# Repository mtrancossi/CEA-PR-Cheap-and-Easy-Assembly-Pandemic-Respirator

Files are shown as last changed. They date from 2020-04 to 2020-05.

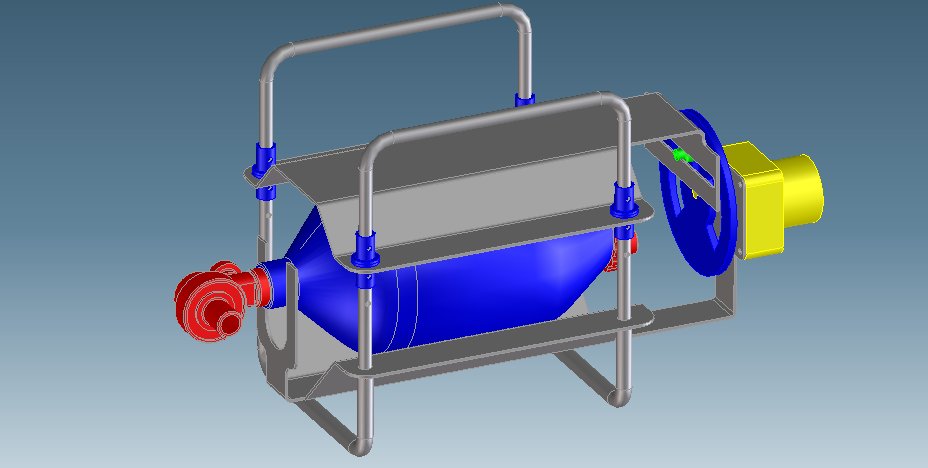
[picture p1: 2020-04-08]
Image3.jpg

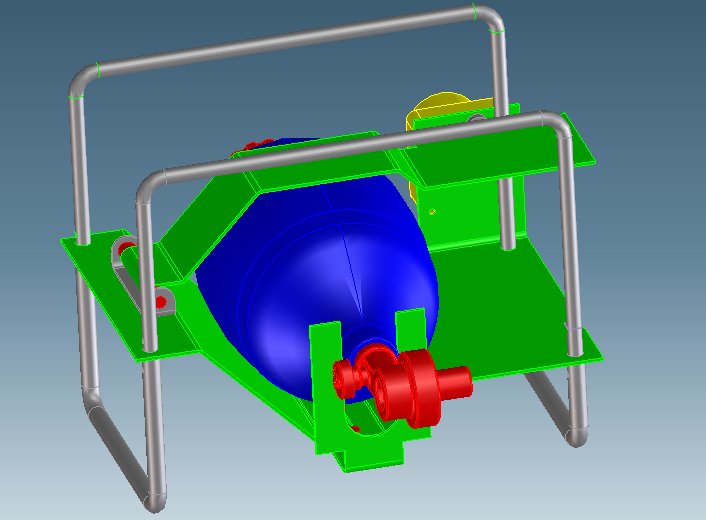
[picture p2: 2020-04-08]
Image13.jpg

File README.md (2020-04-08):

# CEA-PR-Cheap-and-Easy-Assembly-Pandemic-Respirator

This project proposal aim to stimulate the discussion and the work on different models of very traditional and simple pandemic respirators that are simple Ambu actuators that can be manufactured also in poor countries with very traditional technologies.

Details such as screws have not been identified to simplify the drawing of local final versions which could be realized by using locally available items.

The project has been shared open access to ask cooperation in the control area and design improvement. kind regards to anyone who wants to cooperate.

Please notice that when opening into Acrobat the PDF visualization, you need to click on the security bar and recognize the file as secure. otherwise it could not be open and you see only colored balls on the screen.

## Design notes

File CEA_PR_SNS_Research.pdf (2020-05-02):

# CHEAP EASY ASSEMBLY PANDEMIC REPIRATOR

## CEA-PR

## APRIL 19, 2020

SHIVESH NARAYAN SHARMA

Shivesh Narayan Sharma

## Contents

10.2 Calculated values on the basis of different torque and Arm length values (for Pressure

## 1 Abstract

This project proposal aims to stimulate the discussion and the work on different models of very traditional and simple pandemic respirators that are simple Ambu actuators that can be manufactured also in poor countries with very traditional technologies. The ventilation process should be tightly controlled, an uncontrolled pressurization could harm the patient badly and could lead to serious internal injury. This is a preliminary research looking into medical complications of mechanical respiration and improvising the Cheap Easy Assembly Pandemic Respirator (CEA-PR) design in the field of control.

## 2 Hypothesis

The CEA respirator is a motor-operated device, primarily the torque and rpm required to run the machine is an essential value. RPM can be calculated on the basis of no of breathing cycles required in a minute, working out force with help of torque value will help in determining other values. Power of motor can be determined by force and angular velocity.

Compression of Ambu bag plays an essential role in flow rate control, compression can be controlled by force applied pressure control is essential for tidal volume. Both force and pressure can be calculated by velocity and rotating armlength of machine.

Minimum force required to compress the Ambu bag can be identified by using Ideal Gas Law, by identifying internal pressure internal force can be identified. In this case applied force can be assumed greater than the internal force, and further compression calculation can be made. After calculating all the major values pressure, force and RPM can be calculated for execution of a controlled flow rate and tidal volume according to the patient.

## 3 Theory

### 3.1 Medical Point of View

Mechanics of breathing does not allow lungs to inflate like a balloon, when a person breathes his diaphragms contracts along with the intercostal muscles. Which increases the thoracic cavity (the cavity in which lungs resides), this causes increase in volume and decrease in pressure. To equalize the pressure, the lungs expand and equalizes the atmospheric pressure. Hence breathing is control by two muscle groups. The key thing here is that negative pressure initiates the process of inhalation. The exhalation process is exactly reverse of this process, with a small spike above atm to push the air out of the system.

On the other hand, the mechanical ventilation forces the air into the lungs from outside the body and blow lungs like balloon, if this process is not tightly controlled, the air pressure could work against the primary breathing muscles diaphragm and intercostal. This situation could lead to increasing the pressure in the alveoli (over expanding), above their maximum pressure.

Alveoli are the tiny air sacks present in the lungs that are in contact with blood vessels, they are responsible for O2 and CO2 exchange, and diffusion of O2 in the blood. They are very delicate pieces of tissue. The most damage over pressurization could cause is least inflammation, worst rupture. This situation is called Barotrauma. Patients affected by COVID19; in more severe cases it is associated Acute Respiratory Distress Syndrome (ARDS) are more prone to this side effect of mechanical ventilation. The high-end ventilation devices are also controlled very carefully by experienced Doctors, in expensive ventilators the breathing sequence is triggered by the patients.

Other injury due to over pressure, Air to inflate the stomach (gastric insufflation), Lung injury from overstretching (volutrauma).

3.1.1 Tidal Volume
Tidal volume is the air displaced between inspiration and expiration, when no external effort is applied. For a healthy young adult tidal volume is approximately 500 ml per inspiration or 7 ml per kg of body mass. Patients without pre-existing lung disease, VT = 6

ml
kg

to 8

ml
kg

and Respiration rate is 12 to 20 breaths/ min.

Patients with chronic obstructive lung disease requires high enough rate for proper alveolar ventilation, in this case protective lung ventilation applies which ranges from, VT = 6

ml
kg

to 8

ml
kg

and instinct peep does

not create. With ARDS the lung tissues are very vulnerable, permissive hypercapnia technique is applied. In severe cases 5 ml/ kg tidal volume is applied, PH avoids the delivery of high inspiratory pressures and lower the tidal volume. In this situation a higher PEEP is applied, however different types of PEEP levels are required for different situations.

3.1.2 Flow rate
Working out the flow rate for average weighting adult. The average tidal volume is approximately 500 ml per inspiration or 6 to 8 ml/ kg. Normal frequency of breath is 5 to 6 sec per breath, approximately 12 breath per minute. So, calculating flow rate of a 75 kg patient,

Flow rate = Tidal Volume /kg ∗ Respiration rate Equation 1

Protocol states that 15 L/ min flow rate is normal. Keeping control of tidal volume is also important because a higher tidal volume higher than 10 ml/kg increases risk of pulmonary barotrauma.

### 3.2 Engineering point of View

Control of rpm can control compression and volume.

So,

RPM =

Number of Revolution
Time (in minutes)

Equation 2

Speed of the motor is defined for a selected breathing rate, by using rpm value the angular velocity can be calculated,

Angular velocity (ω) =

RPM
60 sec/min

∗ 2π

rad
rev

Equation 3

Linear speed can be calculated by using angular velocity,

v = ω ∗ r Equation 4

Power can be calculated by,

Power (P) = Torque(τ) ∗ AngularVelocity (ω) Equation 5

The calculations present here are theory based, to identify the force applied and power required, first it is the force present inside can be identified. When force and pressure applied will be greater than the inside pressure and force the compression will occur.

For calculating force by using power applied,

Power relates to force and velocity; power is rate of work done,

Pavg = W ∗ ∆t
Equation 6

Work and force have a relation, in our case work done at a constant force,

W = FX∆X Equation 7

where,

FX is force in x direction, ∆X is displacement.

Putting values in, Pavg = W ∗ ∆t
Equation 6

Pavg =

FX∆X

∆t

Pavg = FX

∆X

∆t

where,

∆X

∆t

= Vavg

so,

Pavg = FXVavg

More general outcome or other way,

P = F⃗ ∗ V⃗⃗

P = F ∗ V cos(θ)

If the force and velocity are in the same direction than angle is 0,

cos(0) = 1

So,

P = F ∗ V Equation 8

Pressure applied (Papp) can be calculated by,

Papp =

F
A

Equation 9

Pressure inside the Ambu bag is calculated, here Pin represent pressure inside Ambu bag, Pout represent pressure outside (leaving) the Ambu bag. Similar abbreviation is used in the case of force Fin, Fout, Fapp.

Now for determining the pressure inside the Ambu bag, by using ideal gas law. The temperature used in equation is room temperature 25℃=298.15 K,

By Ideal Gas Law,

PV = nRT

P =

nRT
V

In this case pressure inside,

Pin =

nRT
V

Equation 10

Human respiration is based upon Boyle’s law,

P1V1 = P2V2 Equation 11

## 4 Medical Device Requirement

### 4.1 Complications

One more point which cannot be neglected is due to limited control/ set parameters (cheap ventilators) the entire breathing requirement is analyzed by machine; in this case the patient will take mechanical input weather it is required or not. It is a very uncomfortable and this requires the patient to be heavily sedated. This process could result in worsening the barotrauma, if patient’s diaphragm and intercostal muscles are resisting the inhalation.

### 4.2 Product Design specifications

Table 1 Design specifications

## 5 Device Design

### 5.1 Machine Design

The ventilator consists of two panels, lower panel is fixed and Ambu bag is placed on it. The upper panel is connected with motor on the one side which rotates and on the other side it is connected with hinge mechanism with the lower panel. When rotation takes place the hinge mechanism allows upper panel to move upward and downward, hence the Ambu bag compresses and ventilation takes place.

User specified multiple breath/min settings Multiple tidal volume settings Inspiration/ Expiration ratio Maximum Pressure limiting
Robust Mechanical and Electrical system Minimal Powerd
Provide Mulitple control settings

Medical Requirement

Mechanical

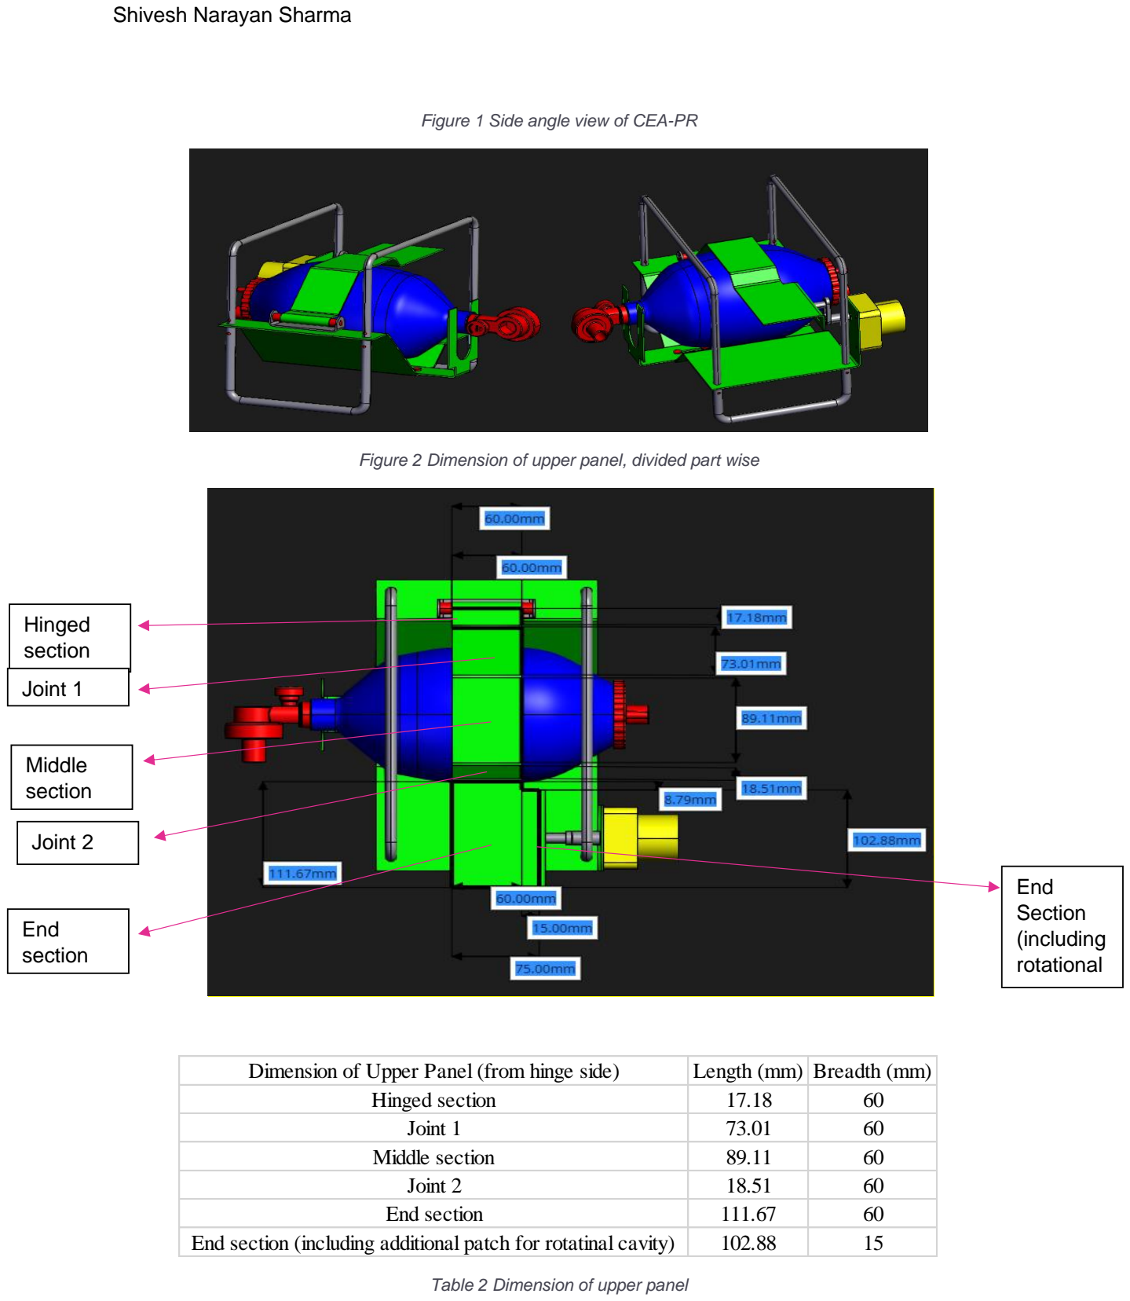
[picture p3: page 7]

Figure 1 Side angle view of CEA-PR

Figure 2 Dimension of upper panel, divided part wise

Table 2 Dimension of upper panel

Dimension of Upper Panel (from hinge side) | Length (mm) | Breadth (mm)
Hinged section | 17.18 | 60
Joint 1 | 73.01 | 60
Middle section | 89.11 | 60
Joint 2 | 18.51 | 60
End section | 111.67 | 60
End section (including additional patch for rotatinal cavity) | 102.88 | 15

Hinged
section

Joint 1

Middle
section

Joint 2

End
section

End
Section
(including
rotational

The sections of upper panel is divided on the basis of joint, it has been divided to understand the dimension of middle section which is creating pressure.

Rotational arm which moves the panel upward and downward = 0.031m = radius of rotating circular path.

### 5.2 Geometry of Ambu Bag

There are two tubing port available on the inlet side, the big port is the reservoir port, small port is for oxygen tubing. On the patient side the expiratory valve is present, for the safety if patient is trying to breath from the other side or putting effort (PEEP valve). Fish mouth valve is present at the patient side, it opens up when the Ambu bag is compressed. For expiration same path is not used, an expiratory duct is present around fish mouth valve. All valves present in the Ambu bag is one-way valves.

Volume of Ambu bag is 1.475 L, according to Ambu website model SPUR II adult resuscitator, with one hand compression releases 800 ml and with two hand compression releases 1100 ml, reservoir volume is 2600 ml and dimension is 295x127 mm.

In this ventilator design Ambu bag can be used with or without oxygen tubing. If patient is critically ill and need 100% of oxygen supply than oxygen tubing can be fitted with reservoir bag. In the case of 100% oxygen delivery if reservoir bag is not attached the open cavity can dilute the oxygen up to 40%, hence the patient will get diluted concentration of oxygen. Whereas using this kit without oxygen supply is also possible as it takes oxygen present in the air.

### 5.3 Selected motor specification

RS Pro Synchronous is the selected motor, the specification is listed below,

Table 3 Specification of motor

## 6 Calculations

The calculation here is based on these values,

Table 4 Values used in calculation

### 6.1 Pressure inside Ambu Bag

From Pin =

nRT
V

Equation 10

Output Speed | 20 rpm
Supply Voltage | 230 V
Maximum Output Torque | 0.016 Nm
Dimension | 60x60x49.5 mm
Gear Ratio | 25:01:00
Weight | 75 Kg
Tidal Volume | 6 ml
Respiration Rate | 12
Temperature | 25˚C (298.15 K)
Torque | 0.016 Nm
Density | 1.225
Radius | 0.031 m

Where,

R = 0.08206, V = 1.475 L (see section description), T = 298.15 K, n (no. of moles) =? ρ =1.225,

no. of moles can be calculated by identifying mass of gas which can identify moles,

so,

m = ρV Equation 12

√V

3 = √1.475 ³

V = 1.3832

Putting value m = ρV Equation 12

m = 1.225 ∗ 1.3832 = 1.80688 gm

= 0.00180688 kg

Air molecular mass = 28.9647 gm/mol

So, by dividing mass of air = 1.80688 gm by molar mass of air 28.9647 gm/ mol we can get no. of moles,

n =

1.80688 gm
28.9647 gm/mol

n = 0.0623821 mol

Substituting the values in eq (10),

Pin =

0.06238 ∗ 0.08206 ∗ 298.15 1.3832

Pin = 1.1278 Pa

Is the pressure present inside the Ambu bag is Pin known, for compression Papp > Pin.

Rpm can be defined by respiratory rate so,

if one round per second,tℎan in a minute = 60 rpm,

by using normal breatℎing rate = 12 breaths per minute (5 sec interval)

= 12 rpm

Flow rate calculation,

Substituting values in Flow rate = Tidal Volume /kg ∗ Respiration rate Equation 1

Taking least here 6 ml per kg so,

= 6

ml
kg ∗ 75kg

= 450 ml = 0.45 L

Flow rate = 0.45 ∗ 12 = 5.41 L/min

Table 5 Flow rate calculated values

Calculating angular velocity on the basis of rpm by equation (3),

ω =

12
60 sec/min

∗ 2π

rad
rev

ω = 1.256 rad/sec

Linear velocity by v = ω ∗ r Equation 4,

v = 1.256 ∗ 0.031 = 0.038

m
s
Calculating Power by Power (P) = Torque(τ) ∗ AngularVelocity (ω) Equation 5

P = 1.256 ∗ 0.016 = 0.020096 W

Force applied (Fapp) can be calculated by P = F ∗ V Equation 8,

Fapp =

0.020096
0.038 = 0.49 N

For Pressure (Papp) by equation (9), value of area is taken from (Table 1) middle section,

Papp =

0.49
0.005346 = 91.65731 Pa

Table 6 Angular velocity, Linear velocity, Power, Applied force and power calculated values.

The pressure value here is applied pressure and force is applied force

Weight | Tidal Volume | RR | Flow Rate
75 | 6 | 12 | 5.4
75 | 6 | 14 | 6.3
75 | 6 | 16 | 7.2
75 | 6 | 18 | 8.1
75 | 6 | 20 | 9
75 | 6 | 22 | 9.9
75 | 6 | 24 | 10.8

Tidal Volume 6

2pi | sec/min | R (m) | Torque (Nm) | RPM | Angular Velocity (rad/sec) | Velocity (m/s) | Power (W) | Force (N) | Area (m^2) | Pressure (Pa)
6.283185307 | 60 | 0.031 | 0.016 | 12 | 1.256637061 | 0.038955749 | 0.020106193 | 0.516129 | 0.005346 | 96.54489941
6.283185307 | 60 | 0.031 | 0.016 | 14 | 1.466076572 | 0.045448374 | 0.023457225 | 0.516129 | 0.005346 | 96.54489941
6.283185307 | 60 | 0.031 | 0.016 | 16 | 1.675516082 | 0.051940999 | 0.026808257 | 0.516129 | 0.005346 | 96.54489941
6.283185307 | 60 | 0.031 | 0.016 | 18 | 1.884955592 | 0.058433623 | 0.030159289 | 0.516129 | 0.005346 | 96.54489941
6.283185307 | 60 | 0.031 | 0.016 | 20 | 2.094395102 | 0.064926248 | 0.033510322 | 0.516129 | 0.005346 | 96.54489941

Arm Length 0.031 m

## 7 Specifications

### 7.1 Machine Control

The primary guidance is to limit the volume and pressure of air entering the lungs. In every action speed of the upper panel of the machine is going to be constant, because more force can lead to more pressure (force is directly proportional to the pressure), which can disturb the flow rate. With constant speed flow rate can be constant. For increase breath/ minute or respiratory rate (RR) interval of the mechanism could be increased. So, Respiration rate can be controlled by rpm, torque value can control applied pressure and force.

In the preliminary research it was found that limiting the compression with the force and pressure was impossible in this kind of mechanism, the compression was the result of rotation. So, in this case it does not matter how much force is applied regardless of the force the arm will rotate and the panel will go downward. It means that the Radius of circular path (R) or the rotating arm controls the compression. For different values of compression (flow rate) the radius of the circular path could decrease (size of the rotating arm could be decreased).

As an Assumption,

if compression by 0.031m rotating arm ≈ two hand compression of ambu bag 1100 ml

that rotating arm size can be assumed by equating, the required flow rate to the upper expression.

So, arm size for a 0.45 L (from the above flow rate calculation),

Let arm size be x,

1.1 L
0.45 L

=

0.031 m
x

x = 0.0126 m.

By this assumption flow rate can be controlled according to the patient’s conditions with multiple possibilities of settings. In this report few rotating arm sizes have been used in calculation and the data has been presented under appendix section. All other required arm sizes can be calculated by using similar approach.

For increase in Tidal volume pressure of the cam can be increased, but speed of the upper panel should be constant, by using pressure compression of the Ambu bag can be controlled which is responsible for tidal volume.

As it can be seen that different tidal volume and weight combinations requires different arm length, in thus case a new design can be introduced based upon watch strap. Where holes can be marked on the scaled positions according to arm length calculation and the little part which moves back and forth on the upper panel. Could be removed and fix (using a nut) to required position.

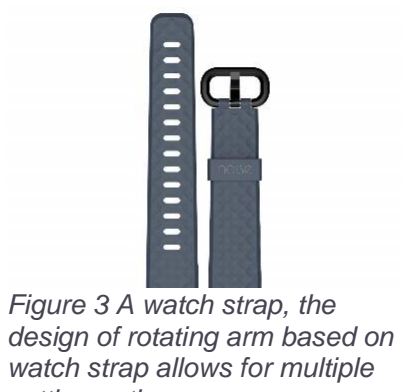
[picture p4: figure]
Figure 3 A watch strap, the design of rotating arm based on watch strap allows for multiple

setting options

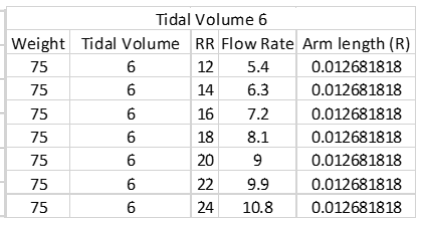
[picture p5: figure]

Table 7 CEA-PR controls | Table 8 Arm length according to flow rate

## 8 Conclusion

The result obtained here are based on the theoretical evaluation. Entire set of result is available in the Appendix section, according to research and calculations the CEA-PR can provide multiple settings of flow rate, tidal volume and pressure control. It can provide aid to an ARDS affected patient which requires low inspiratory pressure and high tidal volume as well as to a patient who requires normal tidal volume and high flow rate. All the data is tabulated according to different weight and different torque values, in which different settings and their outcome which can be achieved by machine is present. The ‘R’ in the table represents radius of the circular path or the rotating arm.

## 9 References

PDS Requirement | Controled Via
User Specified breath/ min | RPM
Tidal volume | Rotational Arm
Maximum Pressure Limiting | Torque
Flow Rate | Rotational Arm
RPM

## 10 Appendix

Radius of circular path or rotating arm length (R) is measured in m.

### 10.1 Calculated flow control and Arm length Value (for compression)

10.1.1 Weight 60

10.1.2 Weight 70

Tidal Volume 5 | Tidal Volume 6
Weight | Tidal Volume | RR | Flow Rate | Arm length (R) | Weight | Tidal Volume | RR | Flow Rate | Arm length (R)
60 | 5 | 12 | 3.6 | 0.008454545 | 60 | 6 | 12 | 4.32 | 0.010145455
60 | 5 | 14 | 4.2 | 0.008454545 | 60 | 6 | 14 | 5.04 | 0.010145455
60 | 5 | 16 | 4.8 | 0.008454545 | 60 | 6 | 16 | 5.76 | 0.010145455
60 | 5 | 18 | 5.4 | 0.008454545 | 60 | 6 | 18 | 6.48 | 0.010145455
60 | 5 | 20 | 6 | 0.008454545 | 60 | 6 | 20 | 7.2 | 0.010145455
60 | 5 | 22 | 6.6 | 0.008454545 | 60 | 6 | 22 | 7.92 | 0.010145455
60 | 5 | 24 | 7.2 | 0.008454545 | 60 | 6 | 24 | 8.64 | 0.010145455
Tidal Volume 7 | Tidal Volume 8
Weight | Tidal Volume | RR | Flow Rate | Arm length (R) | Weight | Tidal Volume | RR | Flow Rate | Arm length (R)
60 | 7 | 12 | 5.04 | 0.011836364 | 60 | 8 | 12 | 5.76 | 0.013527273
60 | 7 | 14 | 5.88 | 0.011836364 | 60 | 8 | 14 | 6.72 | 0.013527273
60 | 7 | 16 | 6.72 | 0.011836364 | 60 | 8 | 16 | 7.68 | 0.013527273
60 | 7 | 18 | 7.56 | 0.011836364 | 60 | 8 | 18 | 8.64 | 0.013527273
60 | 7 | 20 | 8.4 | 0.011836364 | 60 | 8 | 20 | 9.6 | 0.013527273
60 | 7 | 22 | 9.24 | 0.011836364 | 60 | 8 | 22 | 10.56 | 0.013527273
60 | 7 | 24 | 10.08 | 0.011836364 | 60 | 8 | 24 | 11.52 | 0.013527273
Tidal Volume 5 | Tidal Volume 6
Weight | Tidal Volume | RR | Flow Rate | Arm length (R) | Weight | Tidal Volume | RR | Flow Rate | Arm length (R)
70 | 5 | 12 | 4.2 | 0.009863636 | 70 | 6 | 12 | 5.04 | 0.011836364
70 | 5 | 14 | 4.9 | 0.009863636 | 70 | 6 | 14 | 5.88 | 0.011836364
70 | 5 | 16 | 5.6 | 0.009863636 | 70 | 6 | 16 | 6.72 | 0.011836364
70 | 5 | 18 | 6.3 | 0.009863636 | 70 | 6 | 18 | 7.56 | 0.011836364
70 | 5 | 20 | 7 | 0.009863636 | 70 | 6 | 20 | 8.4 | 0.011836364
70 | 5 | 22 | 7.7 | 0.009863636 | 70 | 6 | 22 | 9.24 | 0.011836364
70 | 5 | 24 | 8.4 | 0.009863636 | 70 | 6 | 24 | 10.08 | 0.011836364
Tidal Volume 7 | Tidal Volume 8
Weight | Tidal Volume | RR | Flow rate | Arm length (R) | Weight | Tidal Volume | RR | Flow Rate | Arm length (R)
70 | 7 | 12 | 5.88 | 0.013809091 | 70 | 8 | 12 | 6.72 | 0.015781818
70 | 7 | 14 | 6.86 | 0.013809091 | 70 | 8 | 14 | 7.84 | 0.015781818
70 | 7 | 16 | 7.84 | 0.013809091 | 70 | 8 | 16 | 8.96 | 0.015781818
70 | 7 | 18 | 8.82 | 0.013809091 | 70 | 8 | 18 | 10.08 | 0.015781818
70 | 7 | 20 | 9.8 | 0.013809091 | 70 | 8 | 20 | 11.2 | 0.015781818
70 | 7 | 22 | 10.78 | 0.013809091 | 70 | 8 | 22 | 12.32 | 0.015781818
70 | 7 | 24 | 11.76 | 0.013809091 | 70 | 8 | 24 | 13.44 | 0.015781818

10.1.3 Weight 75

10.1.4 Weight 80

Tidal Volume 5 | Tidal Volume 6
Weight | Tidal Volume | RR | Flow Rate | Arm length (R) | Weight | Tidal Volume | RR | Flow Rate | Arm length (R)
75 | 5 | 12 | 4.5 | 0.010568182 | 75 | 6 | 12 | 5.4 | 0.012681818
75 | 5 | 14 | 5.25 | 0.010568182 | 75 | 6 | 14 | 6.3 | 0.012681818
75 | 5 | 16 | 6 | 0.010568182 | 75 | 6 | 16 | 7.2 | 0.012681818
75 | 5 | 18 | 6.75 | 0.010568182 | 75 | 6 | 18 | 8.1 | 0.012681818
75 | 5 | 20 | 7.5 | 0.010568182 | 75 | 6 | 20 | 9 | 0.012681818
75 | 5 | 22 | 8.25 | 0.010568182 | 75 | 6 | 22 | 9.9 | 0.012681818
75 | 5 | 24 | 9 | 0.010568182 | 75 | 6 | 24 | 10.8 | 0.012681818
Tidal Volume 7 | Tidal Volume 8
Weight | Tidal Volume | RR | Flow rate | Arm length (R) | Weight | Tidal volume | RR | Flow Rate | Arm length (R)
75 | 7 | 12 | 6.3 | 0.014795455 | 75 | 8 | 12 | 7.2 | 0.016909091
75 | 7 | 14 | 7.35 | 0.014795455 | 75 | 8 | 14 | 8.4 | 0.016909091
75 | 7 | 16 | 8.4 | 0.014795455 | 75 | 8 | 16 | 9.6 | 0.016909091
75 | 7 | 18 | 9.45 | 0.014795455 | 75 | 8 | 18 | 10.8 | 0.016909091
75 | 7 | 20 | 10.5 | 0.014795455 | 75 | 8 | 20 | 12 | 0.016909091
75 | 7 | 22 | 11.55 | 0.014795455 | 75 | 8 | 22 | 13.2 | 0.016909091
75 | 7 | 24 | 12.6 | 0.014795455 | 75 | 8 | 24 | 14.4 | 0.016909091
Tidal Volume 5 | Tidal Volume 6
Weight | Tidal Volume | RR | Flow Rate | Arm length (R) | Weight | Tidal Volume | RR | Flow Rate | Arm length (R)
80 | 5 | 12 | 4.8 | 0.011272727 | 80 | 6 | 12 | 5.76 | 0.013527273
80 | 5 | 14 | 5.6 | 0.011272727 | 80 | 6 | 14 | 6.72 | 0.013527273
80 | 5 | 16 | 6.4 | 0.011272727 | 80 | 6 | 16 | 7.68 | 0.013527273
80 | 5 | 18 | 7.2 | 0.011272727 | 80 | 6 | 18 | 8.64 | 0.013527273
80 | 5 | 20 | 8 | 0.011272727 | 80 | 6 | 20 | 9.6 | 0.013527273
80 | 5 | 22 | 8.8 | 0.011272727 | 80 | 6 | 22 | 10.56 | 0.013527273
80 | 5 | 24 | 9.6 | 0.011272727 | 80 | 6 | 24 | 11.52 | 0.013527273
Tidal Volume 7 | | | | | Tidal Volume 8
Weight | Tidal Volume | RR | Flow Rate | Arm length (R) | Weight | Tidal Volume | RR | Flow Rate | Arm length (R)
80 | 7 | 12 | 6.72 | 0.015781818 | 80 | 8 | 12 | 7.68 | 0.018036364
80 | 7 | 14 | 7.84 | 0.015781818 | 80 | 8 | 14 | 8.96 | 0.018036364
80 | 7 | 16 | 8.96 | 0.015781818 | 80 | 8 | 16 | 10.24 | 0.018036364
80 | 7 | 18 | 10.08 | 0.015781818 | 80 | 8 | 18 | 11.52 | 0.018036364
80 | 7 | 20 | 11.2 | 0.015781818 | 80 | 8 | 20 | 12.8 | 0.018036364
80 | 7 | 22 | 12.32 | 0.015781818 | 80 | 8 | 22 | 14.08 | 0.018036364
80 | 7 | 24 | 13.44 | 0.015781818 | 80 | 8 | 24 | 15.36 | 0.018036364

10.1.5 Weight 90

### 10.2 Calculated values on the basis of different torque and Arm length values (for Pressure and Force control)

10.2.1 Torque 0.01
The area mentioned in the table is upper panel Table 2 (middle section) area, Force is applied force and pressure is applied pressure.

10.2.2 Torque 0.012

Tidal Volume 5 | Tidal Volume 6
Weight | Tidal Volume | RR | Flow Rate | Arm length (R) | Weight | Tidal Volume | RR | Flow Rate | Arm length (R)
90 | 5 | 12 | 5.4 | 0.012681818 | 90 | 6 | 12 | 6.48 | 0.015218182
90 | 5 | 14 | 6.3 | 0.012681818 | 90 | 6 | 14 | 7.56 | 0.015218182
90 | 5 | 16 | 7.2 | 0.012681818 | 90 | 6 | 16 | 8.64 | 0.015218182
90 | 5 | 18 | 8.1 | 0.012681818 | 90 | 6 | 18 | 9.72 | 0.015218182
90 | 5 | 20 | 9 | 0.012681818 | 90 | 6 | 20 | 10.8 | 0.015218182
90 | 5 | 22 | 9.9 | 0.012681818 | 90 | 6 | 22 | 11.88 | 0.015218182
90 | 5 | 24 | 10.8 | 0.012681818 | 90 | 6 | 24 | 12.96 | 0.015218182
Tidal Volume 7 | | | | | Tidal Volume 8
Weight | Tidal Volume | RR | Flow rate | Arm length (R) | Weight | Tidal volume | RR | Flow Rate | Arm length (R)
90 | 7 | 12 | 7.56 | 0.017754545 | 90 | 8 | 12 | 8.64 | 0.020290909
90 | 7 | 14 | 8.82 | 0.017754545 | 90 | 8 | 14 | 10.08 | 0.020290909
90 | 7 | 16 | 10.08 | 0.017754545 | 90 | 8 | 16 | 11.52 | 0.020290909
90 | 7 | 18 | 11.34 | 0.017754545 | 90 | 8 | 18 | 12.96 | 0.020290909
90 | 7 | 20 | 12.6 | 0.017754545 | 90 | 8 | 20 | 14.4 | 0.020290909
90 | 7 | 22 | 13.86 | 0.017754545 | 90 | 8 | 22 | 15.84 | 0.020290909
90 | 7 | 24 | 15.12 | 0.017754545 | 90 | 8 | 24 | 17.28 | 0.020290909
2pi | sec/min | R (m) | Torque (Nm) | RPM | Angular Velocity (rad/sec) | Velocity (m/s) | Power (W) | Force (N) | Area (m^2) | Pressure (Pa)
6.283185 | 60 | 0.015 | 0.01 | 12 | 1.256637061 | 0.018849556 | 0.012566371 | 0.666666667 | 0.005346 | 124.7038284
6.283185 | 60 | 0.015 | 0.01 | 14 | 1.466076572 | 0.021991149 | 0.014660766 | 0.666666667 | 0.005346 | 124.7038284
6.283185 | 60 | 0.015 | 0.01 | 16 | 1.675516082 | 0.025132741 | 0.016755161 | 0.666666667 | 0.005346 | 124.7038284
6.283185 | 60 | 0.015 | 0.01 | 18 | 1.884955592 | 0.028274334 | 0.018849556 | 0.666666667 | 0.005346 | 124.7038284
6.283185 | 60 | 0.015 | 0.01 | 20 | 2.094395102 | 0.031415927 | 0.020943951 | 0.666666667 | 0.005346 | 124.7038284

Arm Length 0.015 m

2pi | sec/min | R (m) | Torque (Nm) | RPM | Angular Velocity (rad/sec) | Velocity (m/s) | Power (W) | Force (N) | Area (m^2) | Pressure (Pa)
6.283185 | 60 | 0.02 | 0.01 | 12 | 1.256637061 | 0.025132741 | 0.012566371 | 0.5 | 0.005346 | 93.52787131
6.283185 | 60 | 0.02 | 0.01 | 14 | 1.466076572 | 0.029321531 | 0.014660766 | 0.5 | 0.005346 | 93.52787131
6.283185 | 60 | 0.02 | 0.01 | 16 | 1.675516082 | 0.033510322 | 0.016755161 | 0.5 | 0.005346 | 93.52787131
6.283185 | 60 | 0.02 | 0.01 | 18 | 1.884955592 | 0.037699112 | 0.018849556 | 0.5 | 0.005346 | 93.52787131
6.283185 | 60 | 0.02 | 0.01 | 20 | 2.094395102 | 0.041887902 | 0.020943951 | 0.5 | 0.005346 | 93.52787131

Arm Length 0.02 m

2pi | sec/min | R (m) | Torque (Nm) | RPM | Angular Velocity (rad/sec) | Velocity (m/s) | Power (W) | Force (N) | Area (m^2) | Pressure (Pa)
6.283185 | 60 | 0.031 | 0.01 | 12 | 1.256637061 | 0.038955749 | 0.012566371 | 0.322580645 | 0.005346 | 60.34056213
6.283185 | 60 | 0.031 | 0.01 | 14 | 1.466076572 | 0.045448374 | 0.014660766 | 0.322580645 | 0.005346 | 60.34056213
6.283185 | 60 | 0.031 | 0.01 | 16 | 1.675516082 | 0.051940999 | 0.016755161 | 0.322580645 | 0.005346 | 60.34056213
6.283185 | 60 | 0.031 | 0.01 | 18 | 1.884955592 | 0.058433623 | 0.018849556 | 0.322580645 | 0.005346 | 60.34056213
6.283185 | 60 | 0.031 | 0.01 | 20 | 2.094395102 | 0.064926248 | 0.020943951 | 0.322580645 | 0.005346 | 60.34056213

Arm Length 0.031 m

2pi | sec/min | R (m) | Torque (Nm) | RPM | Angular Velocity (rad/sec) | Velocity (m/s) | Power (W) | Force (N) | Area (m^2) | Pressure (Pa)
6.283185 | 60 | 0.015 | 0.012 | 12 | 1.256637061 | 0.018849556 | 0.015079645 | 0.8 | 0.005346 | 149.6445941
6.283185 | 60 | 0.015 | 0.012 | 14 | 1.466076572 | 0.021991149 | 0.017592919 | 0.8 | 0.005346 | 149.6445941
6.283185 | 60 | 0.015 | 0.012 | 16 | 1.675516082 | 0.025132741 | 0.020106193 | 0.8 | 0.005346 | 149.6445941
6.283185 | 60 | 0.015 | 0.012 | 18 | 1.884955592 | 0.028274334 | 0.022619467 | 0.8 | 0.005346 | 149.6445941
6.283185 | 60 | 0.015 | 0.012 | 20 | 2.094395102 | 0.031415927 | 0.025132741 | 0.8 | 0.005346 | 149.6445941

Arm Length 0.015 m

10.2.3 Torque 0.014

2pi | sec/min | R (m) | Torque (Nm) | RPM | Angular Velocity (rad/sec) | Velocity (m/s) | Power (W) | Force (N) | Area (m^2) | Pressure (Pa)
6.283185 | 60 | 0.02 | 0.012 | 12 | 1.256637061 | 0.025132741 | 0.015079645 | 0.6 | 0.005346 | 112.2334456
6.283185 | 60 | 0.02 | 0.012 | 14 | 1.466076572 | 0.029321531 | 0.017592919 | 0.6 | 0.005346 | 112.2334456
6.283185 | 60 | 0.02 | 0.012 | 16 | 1.675516082 | 0.033510322 | 0.020106193 | 0.6 | 0.005346 | 112.2334456
6.283185 | 60 | 0.02 | 0.012 | 18 | 1.884955592 | 0.037699112 | 0.022619467 | 0.6 | 0.005346 | 112.2334456
6.283185 | 60 | 0.02 | 0.012 | 20 | 2.094395102 | 0.041887902 | 0.025132741 | 0.6 | 0.005346 | 112.2334456

Arm Length 0.02 m

2pi | sec/min | R (m) | Torque (Nm) | RPM | Angular Velocity (rad/sec) | Velocity (m/s) | Power (W) | Force (N) | Area (m^2) | Pressure (Pa)
6.283185 | 60 | 0.031 | 0.012 | 12 | 1.256637061 | 0.038955749 | 0.015079645 | 0.387097 | 0.005346 | 72.40867456
6.283185 | 60 | 0.031 | 0.012 | 14 | 1.466076572 | 0.045448374 | 0.017592919 | 0.387097 | 0.005346 | 72.40867456
6.283185 | 60 | 0.031 | 0.012 | 16 | 1.675516082 | 0.051940999 | 0.020106193 | 0.387097 | 0.005346 | 72.40867456
6.283185 | 60 | 0.031 | 0.012 | 18 | 1.884955592 | 0.058433623 | 0.022619467 | 0.387097 | 0.005346 | 72.40867456
6.283185 | 60 | 0.031 | 0.012 | 20 | 2.094395102 | 0.064926248 | 0.025132741 | 0.387097 | 0.005346 | 72.40867456

Arm Length 0.031 m

2pi | sec/min | R (m) | Torque (Nm) | RPM | Angular Velocity (rad/sec) | Velocity (m/s) | Power (W) | Force (N) | Area (m^2) | Pressure (Pa)
6.283185 | 60 | 0.015 | 0.014 | 12 | 1.256637061 | 0.018849556 | 0.017592919 | 0.933333 | 0.005346 | 174.5853598
6.283185 | 60 | 0.015 | 0.014 | 14 | 1.466076572 | 0.021991149 | 0.020525072 | 0.933333 | 0.005346 | 174.5853598
6.283185 | 60 | 0.015 | 0.014 | 16 | 1.675516082 | 0.025132741 | 0.023457225 | 0.933333 | 0.005346 | 174.5853598
6.283185 | 60 | 0.015 | 0.014 | 18 | 1.884955592 | 0.028274334 | 0.026389378 | 0.933333 | 0.005346 | 174.5853598
6.283185 | 60 | 0.015 | 0.014 | 20 | 2.094395102 | 0.031415927 | 0.029321531 | 0.933333 | 0.005346 | 174.5853598

Arm Length 0.015 m

2pi | sec/min | R (m) | Torque (Nm) | RPM | Angular Velocity (rad/sec) | Velocity (m/s) | Power (W) | Force (N) | Area (m^2) | Pressure (Pa)
6.283185 | 60 | 0.02 | 0.014 | 12 | 1.256637061 | 0.025132741 | 0.017592919 | 0.7 | 0.005346 | 130.9390198
6.283185 | 60 | 0.02 | 0.014 | 14 | 1.466076572 | 0.029321531 | 0.020525072 | 0.7 | 0.005346 | 130.9390198
6.283185 | 60 | 0.02 | 0.014 | 16 | 1.675516082 | 0.033510322 | 0.023457225 | 0.7 | 0.005346 | 130.9390198
6.283185 | 60 | 0.02 | 0.014 | 18 | 1.884955592 | 0.037699112 | 0.026389378 | 0.7 | 0.005346 | 130.9390198
6.283185 | 60 | 0.02 | 0.014 | 20 | 2.094395102 | 0.041887902 | 0.029321531 | 0.7 | 0.005346 | 130.9390198

Arm Length 0.02 m

2pi | sec/min | R (m) | Torque (Nm) | RPM | Angular Velocity (rad/sec) | Velocity (m/s) | Power (W) | Force (N) | Area (m^2) | Pressure (Pa)
6.283185 | 60 | 0.031 | 0.014 | 12 | 1.256637061 | 0.038955749 | 0.017592919 | 0.451613 | 0.005346 | 84.47678699
6.283185 | 60 | 0.031 | 0.014 | 14 | 1.466076572 | 0.045448374 | 0.020525072 | 0.451613 | 0.005346 | 84.47678699
6.283185 | 60 | 0.031 | 0.014 | 16 | 1.675516082 | 0.051940999 | 0.023457225 | 0.451613 | 0.005346 | 84.47678699
6.283185 | 60 | 0.031 | 0.014 | 18 | 1.884955592 | 0.058433623 | 0.026389378 | 0.451613 | 0.005346 | 84.47678699
6.283185 | 60 | 0.031 | 0.014 | 20 | 2.094395102 | 0.064926248 | 0.029321531 | 0.451613 | 0.005346 | 84.47678699

Arm Length 0.031 m

10.2.4 Torque 0.016

2pi | sec/min | R (m) | Torque (Nm) | RPM | Angular Velocity (rad/sec) | Velocity (m/s) | Power (W) | Force (N) | Area (m^2) | Pressure (Pa)
6.283185307 | 60 | 0.015 | 0.016 | 12 | 1.256637061 | 0.018849556 | 0.020106193 | 1.066667 | 0.005346 | 199.5261255
6.283185307 | 60 | 0.015 | 0.016 | 14 | 1.466076572 | 0.021991149 | 0.023457225 | 1.066667 | 0.005346 | 199.5261255
6.283185307 | 60 | 0.015 | 0.016 | 16 | 1.675516082 | 0.025132741 | 0.026808257 | 1.066667 | 0.005346 | 199.5261255
6.283185307 | 60 | 0.015 | 0.016 | 18 | 1.884955592 | 0.028274334 | 0.030159289 | 1.066667 | 0.005346 | 199.5261255
6.283185307 | 60 | 0.015 | 0.016 | 20 | 2.094395102 | 0.031415927 | 0.033510322 | 1.066667 | 0.005346 | 199.5261255

Arm Length 0.015 m

2pi | sec/min | R (m) | Torque (Nm) | RPM | Angular Velocity (rad/sec) | Velocity (m/s) | Power (W) | Force (N) | Area (m^2) | Pressure (Pa)
6.283185307 | 60 | 0.02 | 0.016 | 12 | 1.256637061 | 0.025132741 | 0.020106193 | 0.8 | 0.005346 | 149.6445941
6.283185307 | 60 | 0.02 | 0.016 | 14 | 1.466076572 | 0.029321531 | 0.023457225 | 0.8 | 0.005346 | 149.6445941
6.283185307 | 60 | 0.02 | 0.016 | 16 | 1.675516082 | 0.033510322 | 0.026808257 | 0.8 | 0.005346 | 149.6445941
6.283185307 | 60 | 0.02 | 0.016 | 18 | 1.884955592 | 0.037699112 | 0.030159289 | 0.8 | 0.005346 | 149.6445941
6.283185307 | 60 | 0.02 | 0.016 | 20 | 2.094395102 | 0.041887902 | 0.033510322 | 0.8 | 0.005346 | 149.6445941

Arm Length 0.02 m

2pi | sec/min | R (m) | Torque (Nm) | RPM | Angular Velocity (rad/sec) | Velocity (m/s) | Power (W) | Force (N) | Area (m^2) | Pressure (Pa)
6.283185307 | 60 | 0.031 | 0.016 | 12 | 1.256637061 | 0.038955749 | 0.020106193 | 0.516129 | 0.005346 | 96.54489941
6.283185307 | 60 | 0.031 | 0.016 | 14 | 1.466076572 | 0.045448374 | 0.023457225 | 0.516129 | 0.005346 | 96.54489941
6.283185307 | 60 | 0.031 | 0.016 | 16 | 1.675516082 | 0.051940999 | 0.026808257 | 0.516129 | 0.005346 | 96.54489941
6.283185307 | 60 | 0.031 | 0.016 | 18 | 1.884955592 | 0.058433623 | 0.030159289 | 0.516129 | 0.005346 | 96.54489941
6.283185307 | 60 | 0.031 | 0.016 | 20 | 2.094395102 | 0.064926248 | 0.033510322 | 0.516129 | 0.005346 | 96.54489941

Arm Length 0.031 m

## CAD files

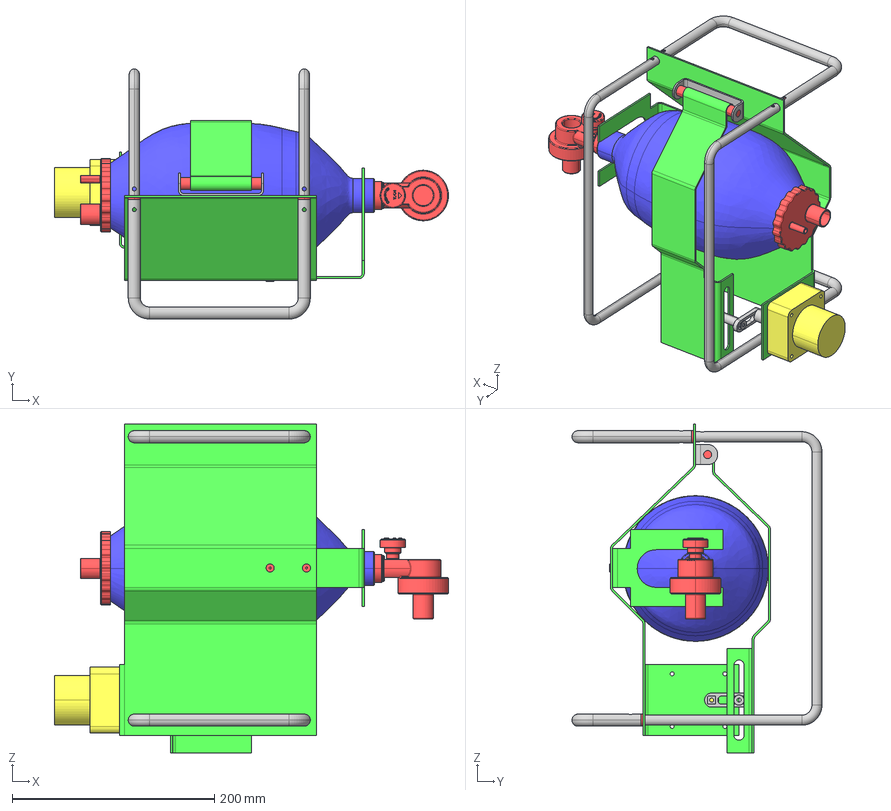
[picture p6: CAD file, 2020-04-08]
Resp5.stp
389.2 x 247.0 x 324.5 mm
Top_Link.2 x 2
pin x 2
p3.2 x 2
pin.1 x 2
a3_a1_Ambubag2.STEP_Ambubag2_butelie_2
a3_a1_Ambubag2.STEP_Ambubag2_ambubag_part
a3_a1_Ambubag2.STEP_Ambubag2_AMBU_BAG1
Sheet.1 x 2
a3_p4.6
Pin_motion
Crank.1
a3_Motor
Crank
Dist
Crank_pin
a3_Motor.1
Dist.3 x 2
Dist.1 x 2
Sheet

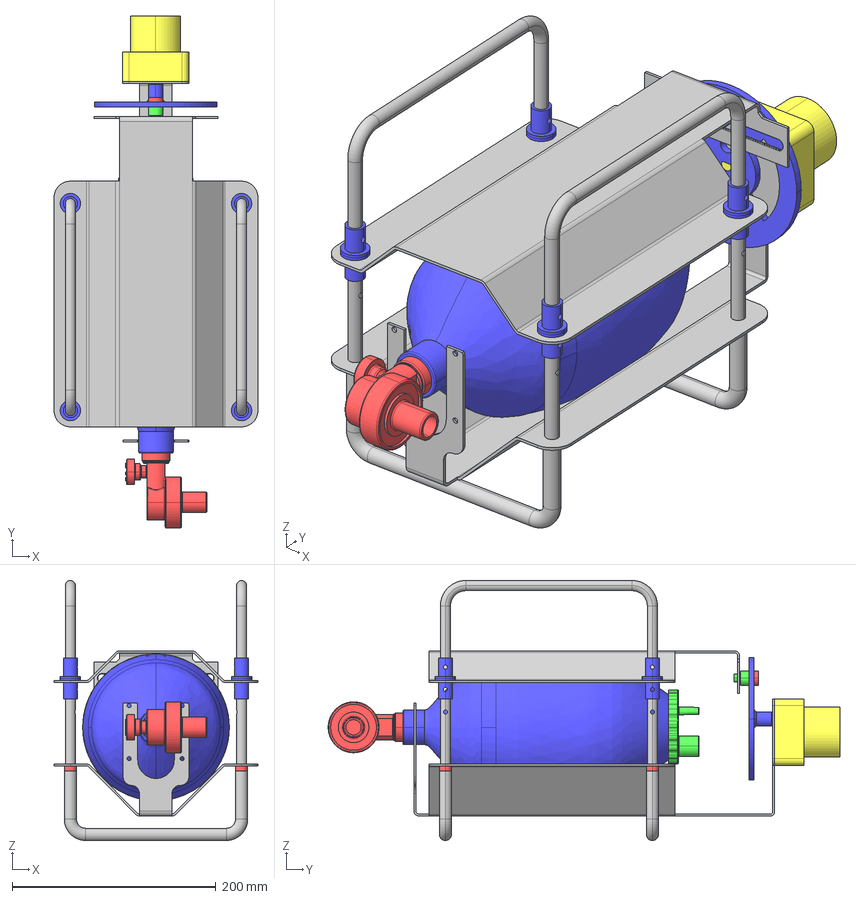
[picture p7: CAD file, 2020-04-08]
RESP3.stp
200.0 x 501.9 x 255.0 mm
Disk_pin
Disk
a3_Motor.1
tubo_top.1.1 x 2
p3.1 x 2
P2.1
p2
bussola1 x 4
boccola_top x 8
Ambubag2.STEP_Ambubag2_AMBU_BAG1
Ambubag2.STEP_Ambubag2_ambubag_part
Ambubag2.STEP_Ambubag2_butelie_2
Disk_pin_2

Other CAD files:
resp3.FCStd
resp5.FCStd

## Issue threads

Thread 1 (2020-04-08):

Possible issues

Pigrenok, 2020-04-08:
Hi, Michele! Nice to hear from you.

I know how badly your country is affected and this ventilator can be a solution. It is very important development in my opinion.

Look, I can see a couple of possible issues with it:
1) You drive the top plate (which is pushing onto Ambu bag) only on one side. This will create significant moment, which will lower the motor side of the plate and raise the other (let's call it valve side) of the plate, effectively constricting it. To avoid it, you need very high precision sliding joints of the top plate and possibly very high quality linear bearings. And that will make the design so much more expensive.
2) As far as I know, Ambu bags are made specifically to be pushed by hands predominantly in the middle. You are pushing it evenly on the whole bag. I believe, the centre of the bag is soft whereas the ends are much more rigid, so, you will need much more power to push it evenly.
3) The other issue is that as far as I know, you need the way to control the pressure (at least to some extent), so, that you will not push to much air into already damaged lungs of a patient. Is there a way to do it?

The first point can be resolved if you are going to pull (or push) the plate in the middle (along the longer side) on both sides.

The second point can be alleviated by making both top and bottom plates convex (towards the bag).

The third on is probably the hardest one, but the pressure can be controlled with fairly simple (yet, it should be fairly reliable and accurate, this needs to be assessed from what is the tolerable pressure difference for patients with pneumonia). The bigger problem is controlling the pressure as at the moment you can control the breathing rate, but not pressure. Possibly, some tricky valve can do it, or the extra expansion bag on the line can do the trick.

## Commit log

2020-04-08 Iges 3d Cad files
    The drawing are release using neutral files to encourage the use of free instruments such as Freecad
2020-04-08 Stp Cad files
    Cad files in STP format
    [RESP3.stp]
2020-04-08 Uploaded the files of the second version
    We have uploaded the second version "compass" because of the kinematic of the system.
    [Resp5.stp]
2020-04-08 Uploaded Free cad Version 1
    [resp3.FCStd]
2020-04-08 Free cad "compass" Version
    [resp5.FCStd]
